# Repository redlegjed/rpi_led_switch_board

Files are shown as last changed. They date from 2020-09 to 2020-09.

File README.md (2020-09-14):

# rpi_led_switch_board

Raspberry Pi LED and switch circuit board

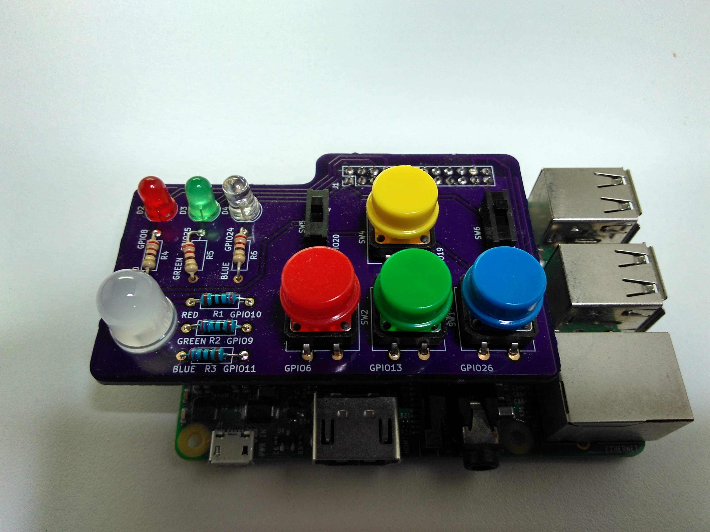
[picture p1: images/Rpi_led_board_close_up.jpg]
LED Board on Rpi


This is a small board that can be fitted on top of the Raspberry Pi GPIO pins. It has the following features;

* 3 individual LEDs
* 1 RGB LED
* 2 slide switches
* 4 push buttons

All of these are separately routed to the Raspberry Pi's GPIO pins through a header so that they can be independently controlled.

Although the board was designed with the Raspberry Pi in mind, there's no reason why it couldn't be used with other similar boards by connecting wires to the relevant header pins.

The board was made as a simple example for learning to use the [Kicad](https://kicad-pcb.org/) circuit board design tools. The design was put together by following [this excellent example from Chris Gammell at Contextual electronics](https://www.youtube.com/watch?v=PlDOnSHkX2c). The Kicad design files are located in the *Rpi_led_switch_board* folder. This folder is a Kicad project so it should be able to be opened directly in Kicad.

The board was fabricated at [Osh Park](https://oshpark.com) and can be viewed [here](https://oshpark.com/shared_projects/ITYO5L7G). 

More details are given below:

# Circuit diagram

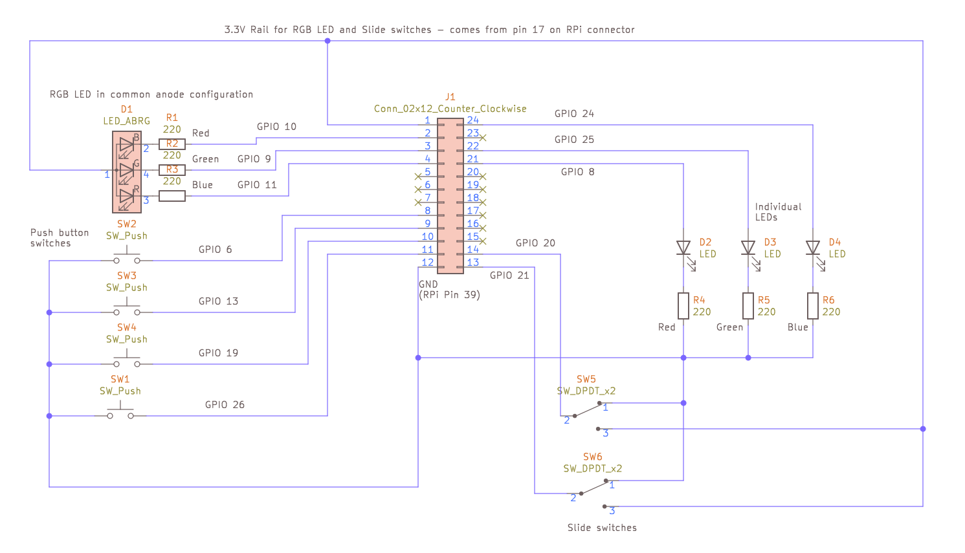
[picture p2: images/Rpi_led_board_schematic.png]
LED Board circuit schematic


The circuit is very basic, it just connects all the components to the header pins. Specifically:

* All push buttons have one side connected to the header (R-Pi GPIO pin) and the other to Ground. 
* The slide switches have 3 pins, one is connected to Ground, one to 3.3V and middle (the slider) goes to the header where it's state can be detected.
* The individual LEDs have their anode (positive, long pin) side connected to the header (GPIO) and their cathode (short pin) to a 220 ohm resistor which goes to Ground.
* The RGB LED is set up as a common anode configuration. This means the positive side of the three LEDs inside it are all connected together and the negative sides come out on three pins. The positive side is connected to 3.3V and the negative sides go through 220 ohm resistors and then to the header (GPIO pins). In common anode configuration the GPIO pins must be set to LOW to turn on the LEDs and HIGH to turn them off. If using the *gpiozero* library *RGBLED* class to control them there is an extra argument needed to setup this. See below and *led_switch_board_demo.py* for examples.

# Components

All the components are available at [Adafruit](https://www.adafruit.com/) but can be found elsewhere as well.

* [Push buttons](https://www.adafruit.com/product/1009)
* [Slide switches](https://www.adafruit.com/product/805)
* [RGB LED 10mm diffused](https://www.adafruit.com/product/848)
* LEDs : any will do
* [220 ohm resistors](https://www.adafruit.com/product/2780)
* [Header](https://www.adafruit.com/product/2222) will need cutting

# Controlling using Python on a Raspberry Pi

The circuit board fits onto one end of the GPIO pin header, the end nearest the USB ports (see picture at the top of this page).

The easiest way to control the board is using the [*gpiozero* library](https://gpiozero.readthedocs.io/en/stable/). Set up all the components like this:

```python
from gpiozero import LED,RGBLED,Button

# Setup the hardware
# =======================

# Individual LEDs
led_red = LED(8)
led_green = LED(25)
led_blue = LED(24)

# Red, Green, Blue (RGB) LED
# Note: need to set the active_high argument to False
led_rgb = RGBLED(red=10,green=9,blue=11,active_high=False)

# Push buttons
button_red = Button(6)
button_green = Button(13)
button_blue = Button(26)
button_yellow = Button(19)

# Slide switches
switch_left = Button(20)
switch_right = Button(21)

```

From here you can use all the functions as described in the *gpiozero* Basic recipes.

```python

# Turn on LED
led_red.on()

# Turn off LED
led_blue.off()

# Set colour on RGB LED
led_rgb.color = (0, 1, 0)  # full green
led_rgb.color = (1, 0, 1)  # magenta
led_rgb.color = (1, 1, 0)  # yellow
led_rgb.color = (0, 1, 1)  # cyan
led_rgb.color = (1, 1, 1)  # white

# Check if button pressed
if button_red.is_pressed:
        print("Red Button is pressed")

# Same for switches
if switch_right.is_pressed:
        print("Right Switch is on")

```

A full example is given in *led_switch_board_demo.py*.

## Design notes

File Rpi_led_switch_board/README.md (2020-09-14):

# Kicad design files

This folder is a Kicad project. It can be opened directly in Kicad using *File/Open Project*.

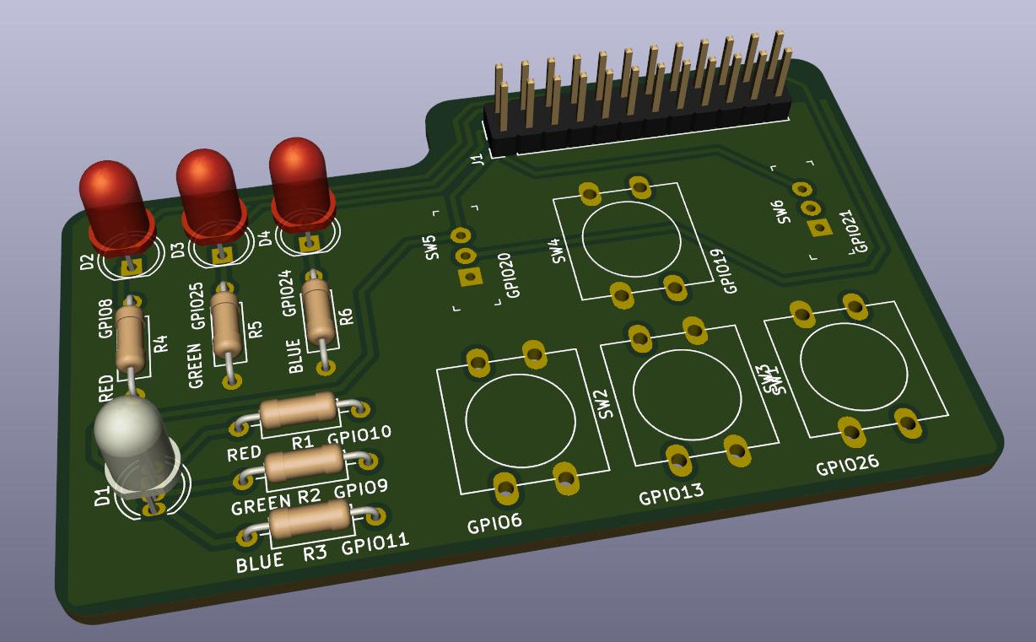
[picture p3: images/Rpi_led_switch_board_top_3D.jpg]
LED Board on Rpi


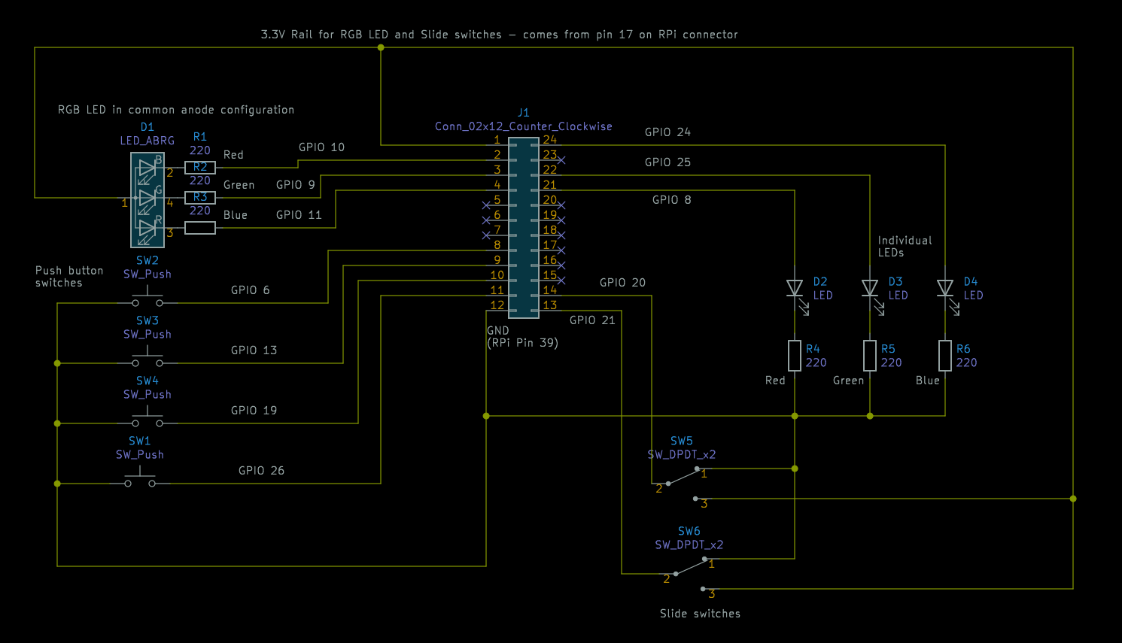
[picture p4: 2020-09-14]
images/Rpi_led_board_schematic_dark.png

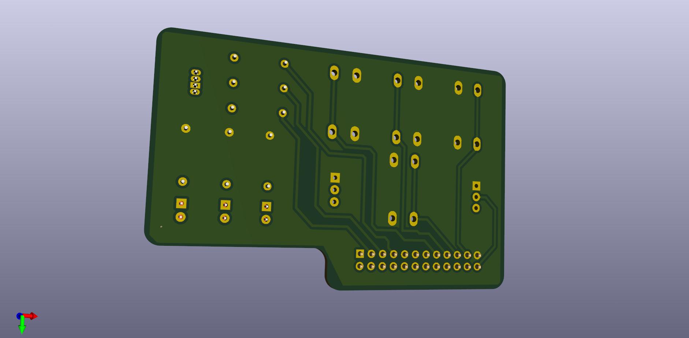
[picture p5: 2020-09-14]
images/Rpi_led_switch_board_bottom_3D.jpg

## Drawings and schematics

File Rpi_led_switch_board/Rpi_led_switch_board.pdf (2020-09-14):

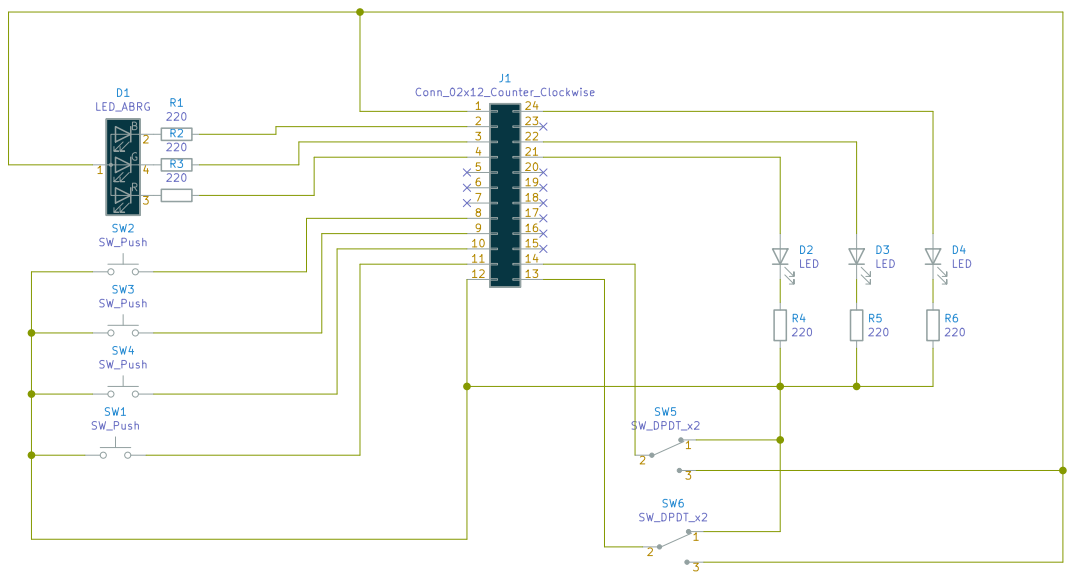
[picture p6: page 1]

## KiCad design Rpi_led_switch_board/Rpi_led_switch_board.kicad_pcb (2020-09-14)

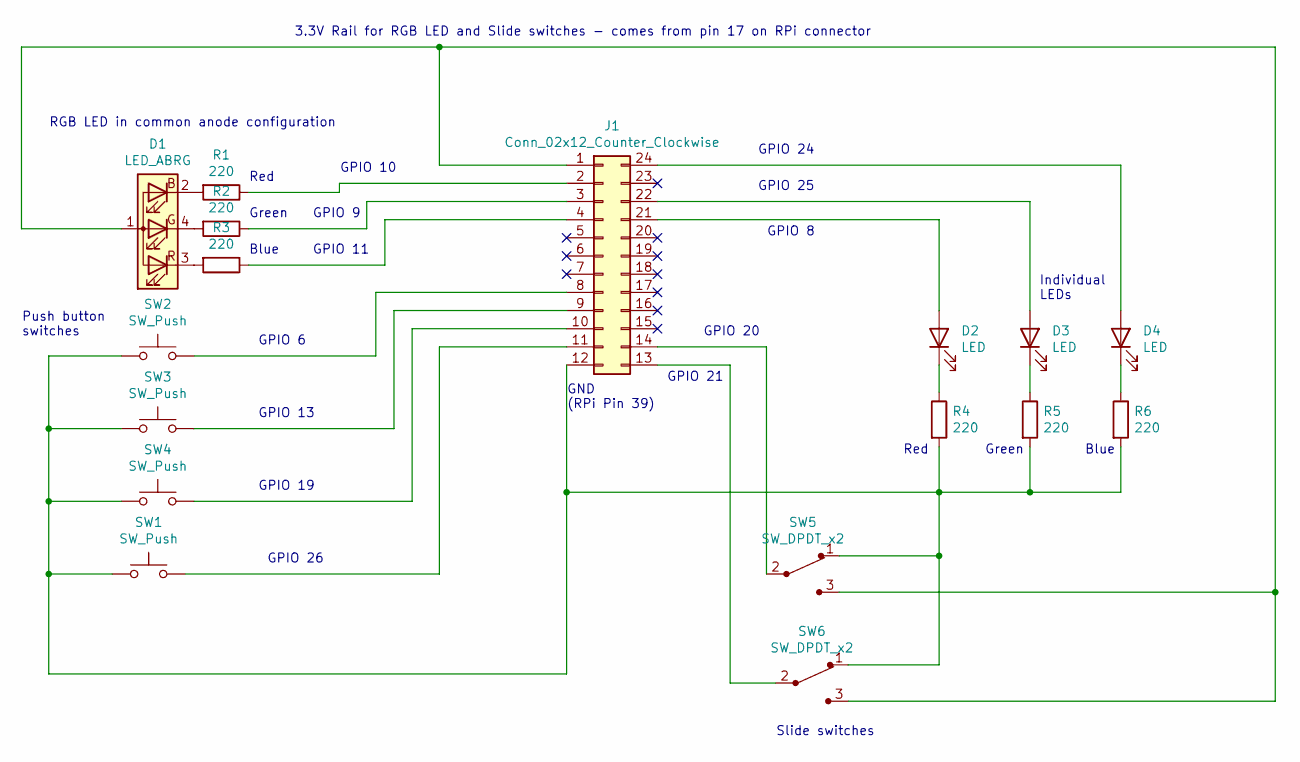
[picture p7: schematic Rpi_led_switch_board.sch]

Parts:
D1: LED_ABRG; LED_D5.0mm-4_RGB
D2, D3, D4: LED; LED_D5.0mm
J1: Conn_02x12_Counter_Clockwise; PinSocket_2x12_P2.54mm_Vertical
R1, R2, R3, R4, R5, R6: 220; R_Axial_DIN0207_L6.3mm_D2.5mm_P10.16mm_Horizontal
SW1, SW2, SW3, SW4: SW_Push; SW_PUSH-12mm
SW5, SW6: SW_DPDT_x2; Switch_Slide_11.6x4mm_EG1218

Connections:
unnamed: D1.1 (A), J1.1, SW5.3, SW6.3
unnamed: D1.2 (BK), R1.2
unnamed: D1.3 (RK), R3.2
unnamed: D1.4 (GK), R2.2
unnamed: D2.1 (K), R4.1
unnamed: D2.2 (A), J1.21
unnamed: D3.1 (K), R5.1
unnamed: D3.2 (A), J1.22
unnamed: D4.1 (K), R6.1
unnamed: D4.2 (A), J1.24
unnamed: J1.2, R1.1
unnamed: J1.3, R2.1
unnamed: J1.4, R3.1
unnamed: J1.8, SW2.2
unnamed: J1.9, SW3.2
unnamed: J1.10, SW4.2
unnamed: J1.11, SW1.2
unnamed: J1.12, R4.2, R5.2, R6.2, SW1.1, SW2.1, SW3.1, SW4.1, SW5.1, SW6.1
unnamed: J1.13, SW6.2
unnamed: J1.14, SW5.2

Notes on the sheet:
3.3V Rail for RGB LED and Slide switches - comes from pin 17 on RPi connector
RGB LED in common anode configuration
Push button switches
Slide switches
Individual LEDs
Red
Green
Blue
GND (RPi Pin 39)
GPIO 20
GPIO 21
GPIO 24
GPIO 25
GPIO 8
GPIO 10
GPIO 9
GPIO 11
GPIO 6
GPIO 13
GPIO 19
GPIO 26

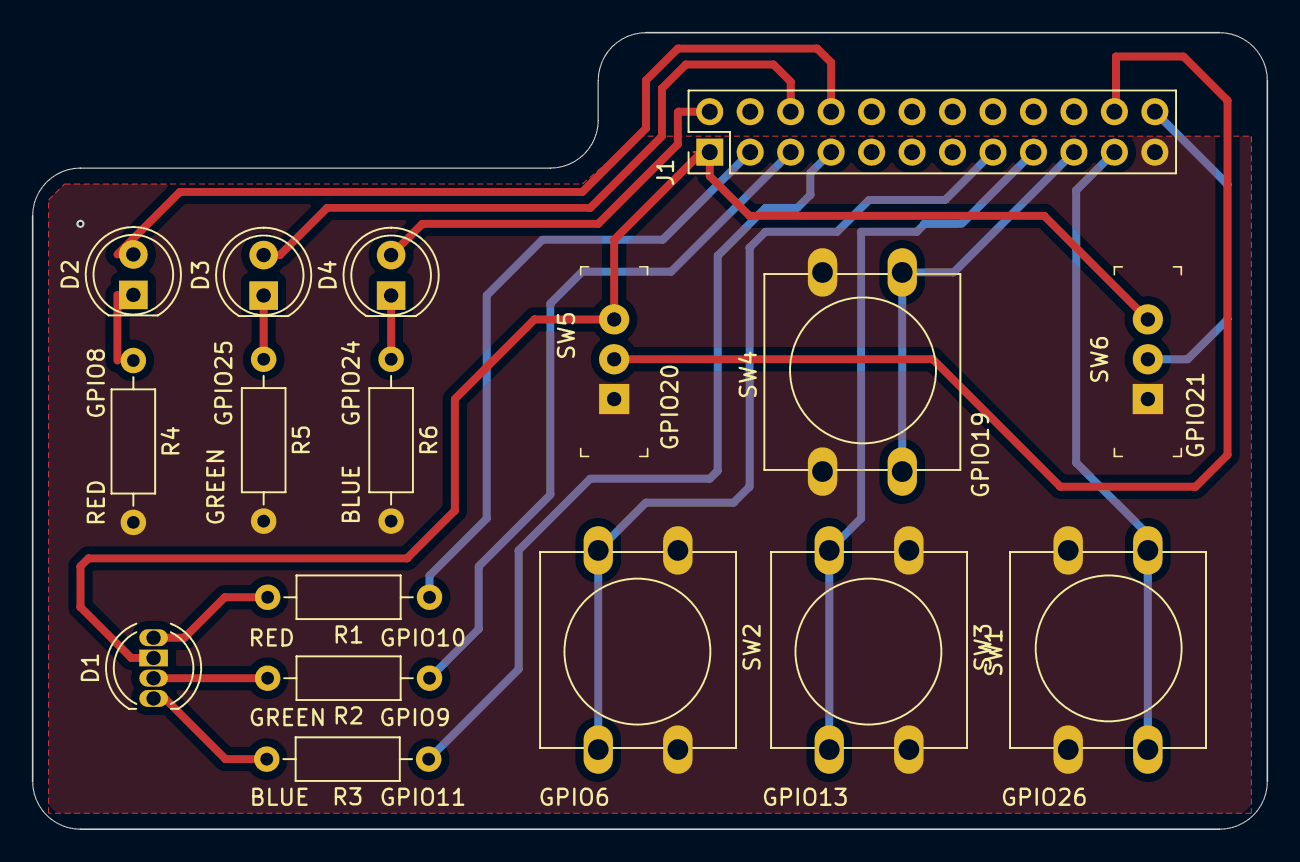
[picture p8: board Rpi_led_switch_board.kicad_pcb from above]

Board: 2 copper layers, 77.5 x 50.0 mm, 17 parts (0 on the bottom side), 20 nets.

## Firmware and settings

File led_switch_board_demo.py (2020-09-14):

"""
LED/Switch board demo

* Set up all the hardware.
* Connect 3 of the push buttons to the individual LEDs. So that the LEDs turn
    on when the buttons are pressed
* Connect 4th button to a function that runs the RGB LED through different colours
* Printout when the slide switches are turned on and off.

See: https://gpiozero.readthedocs.io/en/stable/ for more details

"""

from time import sleep
from gpiozero import LED,RGBLED,Button
from signal import pause

# Setup the hardware
# =======================

# Individual LEDs
led_red = LED(8)
led_green = LED(25)
led_blue = LED(24)

# Red, Green, Blue (RGB) LED
# Note: need to set the active_high argument to False
led_rgb = RGBLED(red=10,green=9,blue=11,active_high=False)

# Push buttons
button_red = Button(6)
button_green = Button(13)
button_blue = Button(26)
button_yellow = Button(19)

# Slide switches
switch_left = Button(20)
switch_right = Button(21)

# Callback functions
def rgb_demo():
 
    led_rgb.color = (0, 1, 0)  # full green
    sleep(1)
    led_rgb.color = (1, 0, 1)  # magenta
    sleep(1)
    led_rgb.color = (1, 1, 0)  # yellow
    sleep(1)
    led_rgb.color = (0, 1, 1)  # cyan
    sleep(1)
    led_rgb.color = (1, 1, 1)  # white
    sleep(1)

    led_rgb.color = (0, 0, 0)  # off
    sleep(1)
    
def switch_on_left():
    print('Left switch is on')
    
def switch_on_right():
    print('Right switch is on')
    
def switch_off_left():
    print('Left switch is off')
    
def switch_off_right():
    print('Right switch is off')
    
    
# Setup connections
# ===================

led_red.source = button_red
led_green.source = button_green
led_blue.source = button_blue

button_yellow.when_pressed = rgb_demo

switch_left.when_pressed = switch_on_left
switch_left.when_released = switch_off_left

switch_right.when_pressed = switch_on_right
switch_right.when_released = switch_off_right

print('Running')
pause()
